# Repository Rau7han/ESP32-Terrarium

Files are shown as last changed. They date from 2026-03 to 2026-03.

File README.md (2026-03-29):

# 🌿 Smart Terrarium — ESP32

> An automated terrarium controller built with ESP32, featuring real-time sensor monitoring, a web dashboard, auto/manual relay control, NeoPixel lighting, and scheduled misting — all in one compact device.

<p align="center">
  Smart Terrarium
</p>

---

## 📖 What Is This?

This project turns a regular terrarium into a smart, self-maintaining environment for plants or reptiles. An ESP32 reads temperature, humidity, and soil moisture, then automatically controls a mist maker, ventilation fan, and water pump to keep everything in the ideal range.

You can monitor and control everything from a browser on your phone or computer — no app install needed.

---

## ✨ Features

- 🌡️ **Live sensor readings** — temperature (DHT11), humidity (DHT11), soil moisture (analog)
- 💧 **3 relay outputs** — Mist Maker, Ventilation Fan, Water Pump
- 🤖 **Auto mode** — relays switch on/off automatically based on your thresholds
- 🕐 **Scheduled misting** — set up to 10 timed mist events per day
- 📊 **Web dashboard** — real-time charts, history graphs, relay toggles, threshold editor
- 💡 **NeoPixel ring (12 LEDs)** — ambient colour shows system status at a glance
- 🖥️ **OLED display** — shows sensor values and relay states without a phone
- ⚡ **OTA (Over-the-Air) firmware updates** — update the code over WiFi, no USB needed
- 💾 **Persistent settings** — thresholds and mode survive power cycles
- 🔘 **Physical button** — short press toggles auto/manual; long press = emergency stop

---

## 🛠️ Hardware You Need

| Component | Details |
|---|---|
| ESP32 dev board | Any 30-pin board works |
| DHT11 sensor | Temperature + humidity |
| Soil moisture sensor | Capacitive or resistive, analog output |
| SSD1306 OLED display | 128×64, I²C |
| NeoPixel LED ring | 12 LEDs, WS2812B |
| 3-channel relay module | 5V, active-HIGH |
| Mist maker / ultrasonic atomiser | 5V or 12V |
| Mini water pump | For soil watering |
| Ventilation fan | 5V or 12V |
| Push button | Momentary, normally open |
| Power supply | 5V or 12V depending on your actuators |

---

## 🔌 Wiring

Connect everything to the ESP32 as follows:

| Signal | ESP32 Pin |
|---|---|
| DHT11 data | GPIO 2 |
| Soil sensor (analog out) | GPIO 36 (ADC1_CH0) |
| Button | GPIO 14 (uses internal pull-up) |
| Relay — Mist Maker | GPIO 25 |
| Relay — Ventilation Fan | GPIO 27 |
| Relay — Water Pump | GPIO 26 |
| NeoPixel data | GPIO 15 |
| OLED SDA | GPIO 5 |
| OLED SCL | GPIO 4 |

> **Note:** All relay outputs are active-HIGH. Connect the relay module's IN pins directly to the GPIO pins listed above.

---

## ⚙️ Software Setup

### 1. Install Arduino IDE and the ESP32 board package

Follow the official guide: [ESP32 Arduino Core](https://docs.espressif.com/projects/arduino-esp32/en/latest/installing.html)

### 2. Install the required libraries

Open **Sketch → Include Library → Manage Libraries** and install:

| Library | Version tested |
|---|---|
| `Adafruit SSD1306` | 2.5.x |
| `Adafruit GFX Library` | 1.11.x |
| `DHT sensor library` (Adafruit) | 1.4.x |
| `Adafruit NeoPixel` | 1.11.x |
| `ArduinoJson` | 6.x |

The following libraries come with the ESP32 board package and don't need separate installation: `WiFi`, `WebServer`, `ArduinoOTA`, `Preferences`.

### 3. Configure your WiFi credentials

Open `code/terrarium.ino` and update these two lines near the top:

```cpp
const char* WIFI_SSID = "YourNetworkName";
const char* WIFI_PASS = "YourPassword";
```

If you're not in India, also update the timezone offset (in seconds from UTC):

```cpp
const long GMT_OFFSET = 19800;  // IST = UTC+5:30  →  change to match your zone
```

### 4. Flash the ESP32

1. Connect the ESP32 via USB
2. Select your board: **Tools → Board → ESP32 Dev Module**
3. Select the correct COM port
4. Click **Upload**

### 5. Open the dashboard

1. Open the Serial Monitor at 115200 baud
2. Wait for the IP address to appear (e.g. `[WiFi] IP: 192.168.1.42`)
3. Type that address into any browser on the same network

> After the first flash you can update firmware wirelessly via **Sketch → Upload Using Programmer → OTA** — the device shows up as `terrarium-esp32`.

---

## 📟 OLED Display

The OLED cycles between two screens every 4 seconds:

| Screen | Shows |
|---|---|
| Page 1 | Temperature, Humidity, Soil moisture (with progress bar) |
| Page 2 | Relay states (Mist / Fan / Pump), WiFi status |

A mode indicator (`[AUTO]` or `[MANU]`) appears in the top corner at all times.

---

## 💡 NeoPixel Colour Guide

The 12 LEDs give you a quick at-a-glance status without looking at a screen:

| Colour | Meaning |
|---|---|
| 🟣 Purple | System is OK — all readings in range |
| 🔵 Blue (pixels 0–1) | Mist maker is ON |
| 🟠 Orange (pixels 4–5) | Fan is ON |
| 🩵 Cyan (pixels 8–9) | Pump is ON |
| 🔴 Red | Sensor error — check DHT11 |
| 🔵 Blue (ambient) | Soil is too dry |
| 🟢 Green | Soil is too wet |
| 🟠 Orange (ambient) | Temperature is too high |

---

## 🔘 Physical Button

| Press | Action |
|---|---|
| Short press | Toggle between Auto and Manual mode |
| Long press (2 s+) | Emergency stop — all relays turn OFF immediately |

---

## 🌐 Web Dashboard

Type the ESP32's IP address into any browser to open the dashboard. No app or internet connection needed — it runs entirely on the device.

<p align="center">
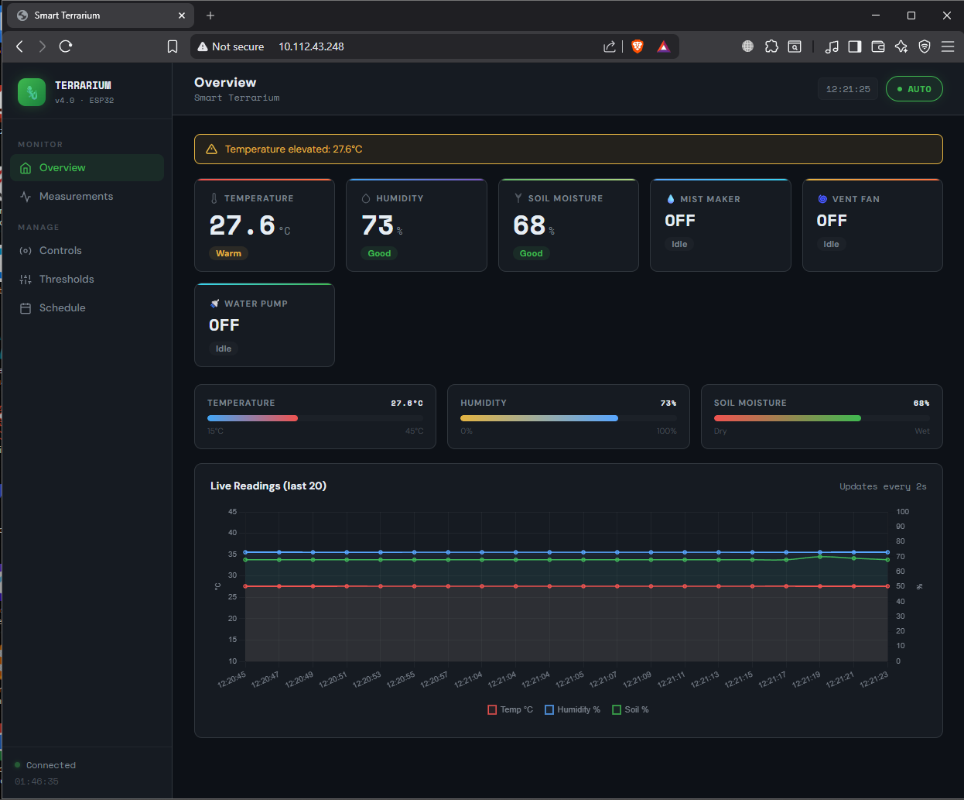
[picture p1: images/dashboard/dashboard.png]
Main Dashboard
  
  <br><em>Main dashboard — live sensor cards update every 2 seconds</em>
</p>

<p align="center">
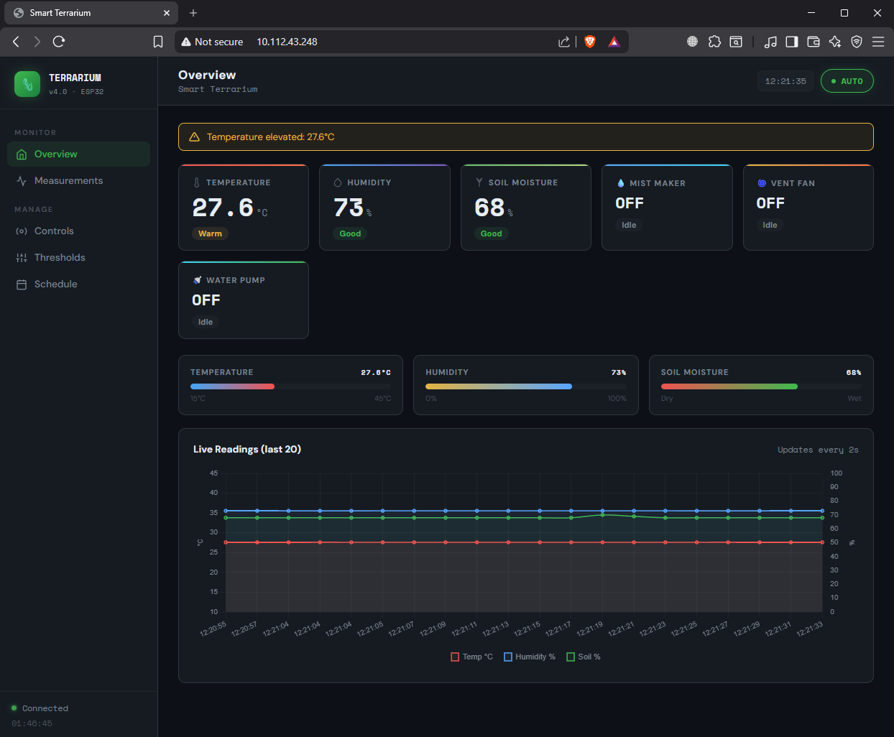
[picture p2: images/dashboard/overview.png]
Overview Panel
  
  <br><em>Overview panel showing all sensor and relay status</em>
</p>

<p align="center">
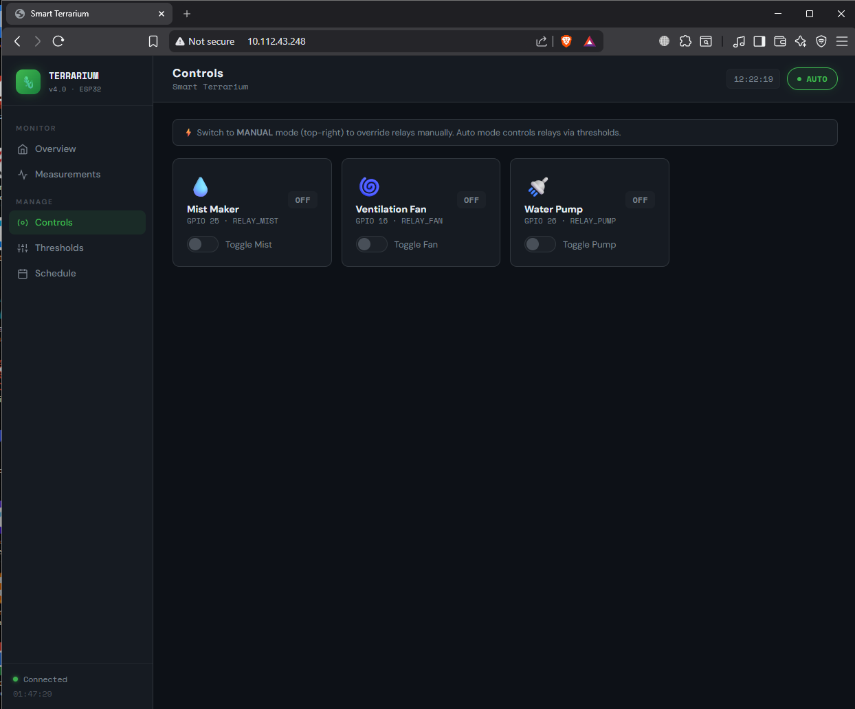
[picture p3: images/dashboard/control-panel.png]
Control Panel
  
  <br><em>Manual relay control panel — toggle Mist, Fan, and Pump individually</em>
</p>

### Sensor History Charts

<p align="center">
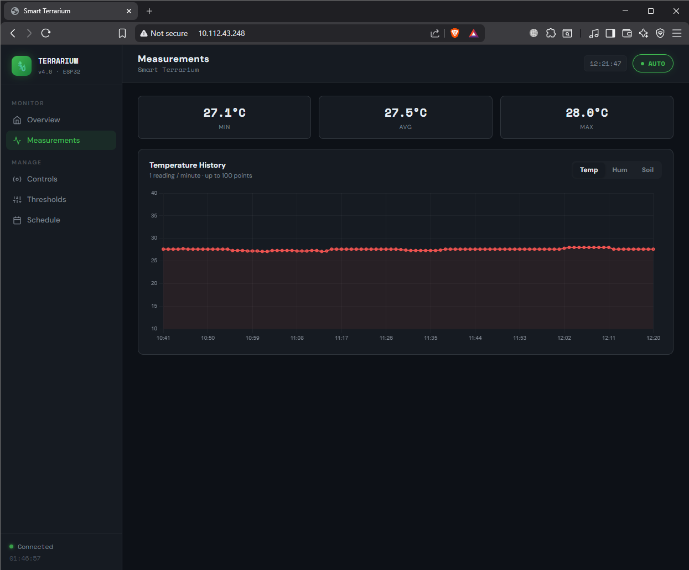
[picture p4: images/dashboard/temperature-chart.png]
Temperature History
  
  <br><em>Temperature history — one data point per minute, last 100 readings</em>
</p>

<p align="center">
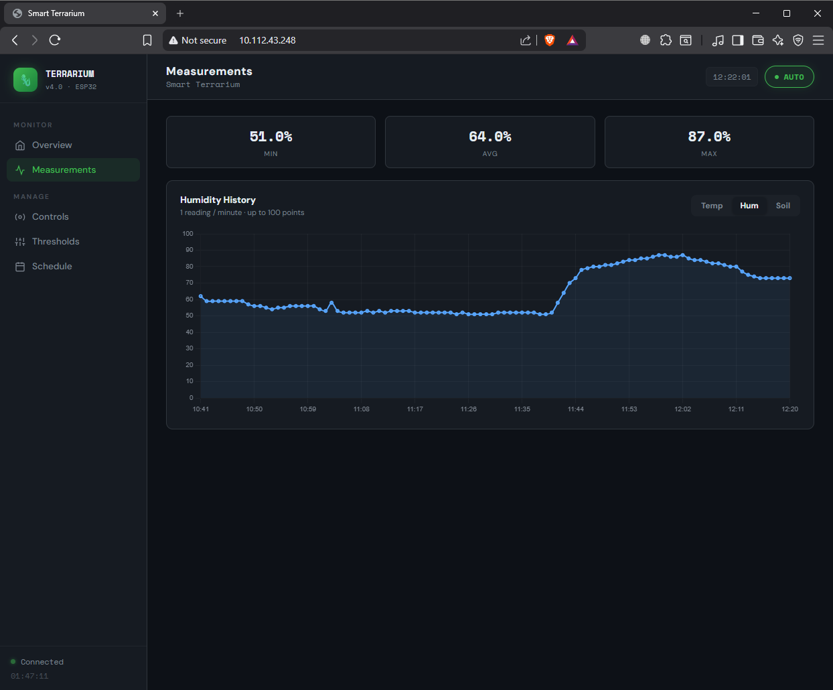
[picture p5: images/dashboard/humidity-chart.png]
Humidity History
  
  <br><em>Humidity history chart</em>
</p>

<p align="center">
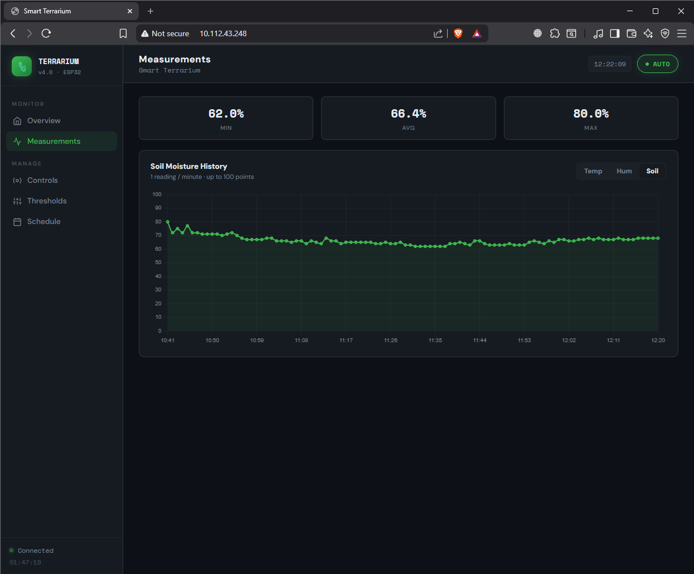
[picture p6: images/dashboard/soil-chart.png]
Soil Moisture History
  
  <br><em>Soil moisture history chart</em>
</p>

### Threshold Settings

<p align="center">
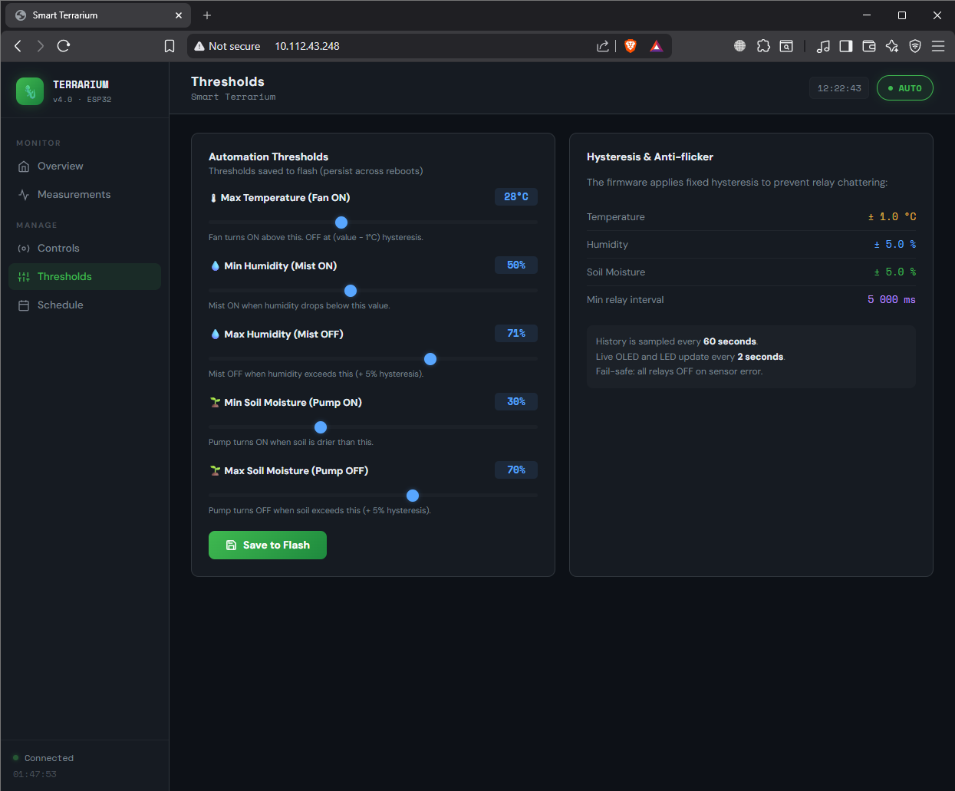
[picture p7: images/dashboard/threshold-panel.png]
Threshold Settings
  
  <br><em>Set your ideal ranges — values are saved to flash and survive power cuts</em>
</p>

### Scheduled Misting

<p align="center">
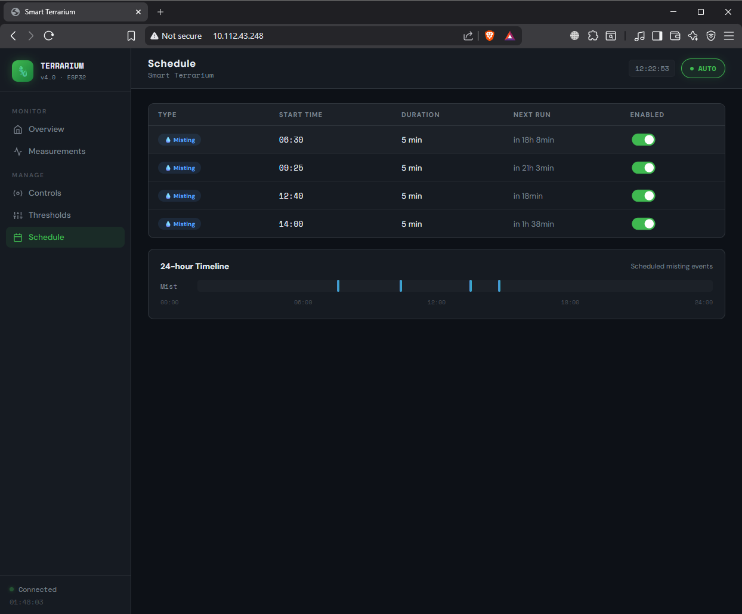
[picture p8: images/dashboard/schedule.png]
Misting Schedule
  
  <br><em>Schedule up to 10 daily misting events with custom duration</em>
</p>

---

## 📷 It Working in Real Life

<p align="center">
  Full Setup Running
  <br><em>The complete setup running — OLED lit, NeoPixels on</em>
</p>

<p align="center">
  Temperature Reading
  &nbsp;&nbsp;
  Humidity Reading
  <br><em>Left: temperature reading on the OLED &nbsp;|&nbsp; Right: humidity reading</em>
</p>

<p align="center">
  Soil Moisture Reading
  &nbsp;&nbsp;
  Threshold Display
  <br><em>Left: soil moisture sensor in action &nbsp;|&nbsp; Right: threshold display</em>
</p>

---

## 🖨️ 3D Printed Parts

The `3D_files/` folder contains an STL file for a custom **Aromizer housing** (`Aromizer.stl`) that mounts the ultrasonic mist maker neatly inside the terrarium.

---

## 📡 REST API Reference

The ESP32 exposes a simple JSON API, useful if you want to integrate it with Home Assistant or build your own UI.

| Method | Endpoint | Description |
|---|---|---|
| `GET` | `/api/live` | Current sensor readings and relay states |
| `GET` | `/api/history` | Last 100 readings (1 per minute) |
| `GET` | `/api/thresholds` | Current threshold values |
| `POST` | `/api/thresholds` | Update threshold values |
| `POST` | `/api/relay` | Turn a relay on/off (manual mode only) |
| `POST` | `/api/mode` | Switch between auto and manual mode |
| `GET` | `/api/events` | List scheduled misting events |
| `POST` | `/api/events` | Add or update a misting event |

**Example — read live data:**
```bash
curl http://192.168.1.42/api/live
```

**Example — turn on mist manually:**
```bash
curl -X POST http://192.168.1.42/api/relay \
     -H "Content-Type: application/json" \
     -d '{"relay":"mist","state":true}'
```

---

## 📁 Repository Structure

```
ESP32-Terrarium/
├── code/
│   └── terrarium.ino          # Main Arduino sketch
├── images/
│   ├── hardware/              # Real photos of the device
│   └── dashboard/             # Dashboard screenshots
├── 3D_files/
│   └── Aromizer.stl           # 3D printable mist maker housing
└── README.md
```

---

## 🤝 Contributing

Pull requests are welcome! If you add a new feature or fix a bug, please keep the code style consistent (the existing comments and section separators make it easy to follow).

---

## 📜 License

This project is open source. Feel free to use, modify, and share it for personal or educational purposes.

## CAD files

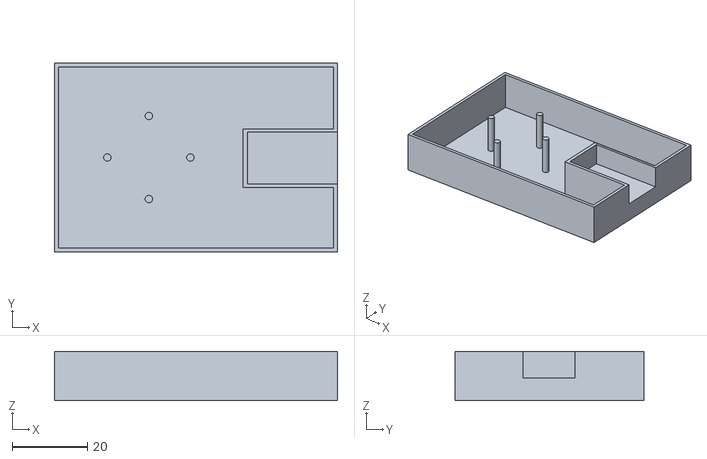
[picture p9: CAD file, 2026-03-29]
3D_files/Aromizer.stl
75.0 x 50.0 x 13.0

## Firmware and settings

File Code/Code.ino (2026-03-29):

// ╔══════════════════════════════════════════════════════════════╗
// ║          SMART TERRARIUM v4.0 — ESP32                       ║
// ║  Features: DHT11 · Soil · OLED · NeoPixel · 3x Relay       ║
// ║  WiFi Dashboard · Auto/Manual · Scheduled Misting    ║
// ╚══════════════════════════════════════════════════════════════╝

// ── Libraries ──────────────────────────────────────────────────
#include <Wire.h>
#include <Adafruit_GFX.h>
#include <Adafruit_SSD1306.h>
#include <DHT.h>
#include <Adafruit_NeoPixel.h>
#include <WiFi.h>
#include <WebServer.h>
#include <ArduinoJson.h>
#include <ArduinoOTA.h>
#include <Preferences.h>
#include <time.h>

// ── OLED ───────────────────────────────────────────────────────
#define I2C_SDA      5
#define I2C_SCL      4
#define OLED_W     128
#define OLED_H      64
Adafruit_SSD1306 display(OLED_W, OLED_H, &Wire, -1);

// ── DHT ────────────────────────────────────────────────────────
#define DHTPIN   2
#define DHTTYPE  DHT11
DHT dht(DHTPIN, DHTTYPE);

// ── Pins ───────────────────────────────────────────────────────
#define SOIL_PIN    36   // ADC1_CH0 — input-only
#define BUTTON_PIN  14   // INPUT_PULLUP
#define RELAY_MIST  25   // Mist Maker
#define RELAY_FAN   27   // Ventilation Fan
#define RELAY_PUMP  26   // Water Pump (NEW)
#define NEO_PIN     15   // NeoPixel data
#define NEO_COUNT   12

// ── Soil ADC calibration ───────────────────────────────────────
#define SOIL_DRY   4095
#define SOIL_WET   1800

// ── NeoPixel ───────────────────────────────────────────────────
Adafruit_NeoPixel ring(NEO_COUNT, NEO_PIN, NEO_GRB + NEO_KHZ800);

// ── WiFi / NTP ─────────────────────────────────────────────────
const char* WIFI_SSID   = "ESP";
const char* WIFI_PASS   = "abcd1234";
const char* NTP_SERVER  = "pool.ntp.org";
const long  GMT_OFFSET  = 19800;   // IST = UTC+5:30
const int   DST_OFFSET  = 0;

WebServer   server(80);
Preferences prefs;
bool        ntpSynced = false;

// ── Timing constants ───────────────────────────────────────────
// One reading per minute stored in history; live display refreshes every 2s
const unsigned long SENSOR_INTERVAL  = 60000UL;  // 60 s — history samples
const unsigned long LIVE_INTERVAL    = 2000UL;   // 2 s  — live readings (OLED/LED)
const unsigned long DISPLAY_INTERVAL = 500UL;    // 0.5 s — OLED refresh

// Relay anti-flicker: minimum ms between toggling the same relay
const unsigned long RELAY_MIN_INTERVAL = 5000UL; // 5 s

// ── Hysteresis ─────────────────────────────────────────────────
// Applied on top of threshold values so relays don't rapid-toggle
// Fan ON  if temp > tempMax,  OFF if temp < tempMax - TEMP_HYST
// Mist ON if hum  < humMin,   OFF if hum  > humMin  + HUM_HYST
// Pump ON if soil < soilMin,  OFF if soil > soilMin + SOIL_HYST
#define TEMP_HYST   1.0f   // °C
#define HUM_HYST    5.0f   // %
#define SOIL_HYST   5      // %

// ── Sensor data ────────────────────────────────────────────────
struct Reading {
    float    temp;
    float    hum;
    int      soil;
    uint32_t epoch;  // Unix timestamp (or seconds since boot)
};

#define HIST_SIZE 100
Reading  history[HIST_SIZE];
int      histHead  = 0;
int      histCount = 0;

struct Live {
    float temp  = 0;
    float hum   = 0;
    int   soil  = 0;
    bool  dhtOk = false;
};
Live live;

// ── Relay state ────────────────────────────────────────────────
struct Relays {
    bool mist = false;
    bool fan  = false;
    bool pump = false;
};
Relays relays;

// Anti-flicker: last time each relay was toggled
unsigned long lastToggleMist = 0;
unsigned long lastToggleFan  = 0;
unsigned long lastTogglePump = 0;

// ── Mode ───────────────────────────────────────────────────────
bool autoMode = false;

// ── Auto thresholds (persistent) ──────────────────────────────
struct Thresholds {
    float tempMax  = 30.0f;
    float humMin   = 50.0f;
    float humMax   = 80.0f;
    int   soilMin  = 30;
    int   soilMax  = 70;
};
Thresholds thresh;

// ── Scheduled misting events ───────────────────────────────────
#define MAX_EVENTS 10
struct MistEvent {
    int  hour;
    int  minute;
    int  durationMin;
    bool enabled;
};
MistEvent mistEvents[MAX_EVENTS] = {
    { 6, 30, 5, true },
    { 9, 25, 5, true },
    {12, 40, 5, true },
    {14,  0, 5, true },
};
int           eventCount = 4;
unsigned long mistStopAt = 0;

// ── Button debounce ────────────────────────────────────────────
const unsigned long DEBOUNCE_MS   = 50;
const unsigned long LONG_PRESS_MS = 2000;

bool          btnRaw      = false;
bool          btnStable   = false;
bool          btnDown     = false;
unsigned long btnDownAt   = 0;
unsigned long btnDebounce = 0;

// ── Timing trackers ────────────────────────────────────────────
unsigned long lastSensor  = 0;   // history write
unsigned long lastLive    = 0;   // live read (OLED / LED)
unsigned long lastDisplay = 0;   // OLED repaint

// ── OLED animation ────────────────────────────────────────────
int oledPage = 0;   // 0=overview, 1=relays, cycles every 4 s

// ── Forward declarations ───────────────────────────────────────
void connectWiFi();
void syncNTP();
String timestamp();
uint32_t epochNow();
void loadPrefs();
void savePrefs();
void setupRoutes();
void sendJSON(int code, const String& j);
void readSensors();
void runAutoControl();
void checkScheduledMisting();
void setRelay(bool& state, int pin, bool on, const char* name, unsigned long& lastToggle);
void handleButton();
void updateOLED();
void updateNeoPixel();
void printBanner();

// ════════════════════════════════════════════════════════════════
//  SETUP
// ════════════════════════════════════════════════════════════════
void setup() {
    Serial.begin(115200);
    delay(300);
    printBanner();

    // Persistent storage
    prefs.begin("terrarium", false);
    loadPrefs();

    // I2C + OLED
    Wire.begin(I2C_SDA, I2C_SCL);
    delay(80);
    bool oledOk = display.begin(SSD1306_SWITCHCAPVCC, 0x3C);
    if (!oledOk) Serial.println("[OLED] Init failed");
    display.setTextColor(WHITE);
    display.clearDisplay();
    display.setTextSize(1);
    display.setCursor(0,  0); display.println("SMART TERRARIUM v4");
    display.setCursor(0, 12); display.println("Initializing...");
    display.display();

    // Sensors
    dht.begin();
    analogSetPinAttenuation(SOIL_PIN, ADC_11db);

    // NeoPixel
    ring.begin(); ring.clear(); ring.show();

    // Button
    pinMode(BUTTON_PIN, INPUT_PULLUP);

    // Relays — ALL OFF at start (fail-safe)
    pinMode(RELAY_MIST, OUTPUT); digitalWrite(RELAY_MIST, LOW);
    pinMode(RELAY_FAN,  OUTPUT); digitalWrite(RELAY_FAN,  LOW);
    pinMode(RELAY_PUMP, OUTPUT); digitalWrite(RELAY_PUMP, LOW);

    // WiFi
    connectWiFi();

    if (WiFi.status() == WL_CONNECTED) {
        display.clearDisplay();
        display.setTextSize(1);
        display.setCursor(0,  0); display.println("WiFi Connected!");
        display.setCursor(0, 12); display.println("IP:");
        display.setTextSize(1);
        display.setCursor(0, 22); display.println(WiFi.localIP().toString());
        display.display();
        delay(2000);
    }

    syncNTP();

    // OTA
    ArduinoOTA.setHostname("terrarium-esp32");
    ArduinoOTA.onStart([]() {
        relays.mist = relays.fan = relays.pump = false;
        digitalWrite(RELAY_MIST, LOW);
        digitalWrite(RELAY_FAN,  LOW);
        digitalWrite(RELAY_PUMP, LOW);
        Serial.println("[OTA] Starting...");
    });
    ArduinoOTA.begin();

    setupRoutes();
    server.begin();

    // Do one immediate live read so OLED isn't blank
    readSensors(true);

    Serial.println("[SETUP] Complete");
}

// ════════════════════════════════════════════════════════════════
//  LOOP
// ════════════════════════════════════════════════════════════════
void loop() {
    ArduinoOTA.handle();
    server.handleClient();
    handleButton();

    unsigned long now = millis();

    // ── Live read every 2 s (for OLED / NeoPixel / auto-control) ──
    if (now - lastLive >= LIVE_INTERVAL) {
        readSensors(false);   // false = don't push to history
        if (autoMode)  runAutoControl();
        if (ntpSynced) checkScheduledMisting();

        // Stop scheduled mist when timer expires
        if (mistStopAt && now >= mistStopAt) {
            setRelay(relays.mist, RELAY_MIST, false, "Mist(sched-stop)", lastToggleMist);
            mistStopAt = 0;
        }
        lastLive = now;
    }

    // ── History write every 60 s ───────────────────────────────
    if (now - lastSensor >= SENSOR_INTERVAL) {
        // Push current live reading into history ring buffer
        Reading r;
        r.temp  = live.temp;
        r.hum   = live.hum;
        r.soil  = live.soil;
        r.epoch = epochNow();
        history[histHead] = r;
        histHead = (histHead + 1) % HIST_SIZE;
        if (histCount < HIST_SIZE) histCount++;
        Serial.printf("[History] Stored %.1f°C  %.0f%%  Soil:%d%%\n", live.temp, live.hum, live.soil);
        lastSensor = now;
    }

    // ── OLED + LED refresh ────────────────────────────────────
    if (now - lastDisplay >= DISPLAY_INTERVAL) {
        updateOLED();
        updateNeoPixel();
        lastDisplay = now;
    }

    // ── Non-blocking WiFi reconnect ───────────────────────────
    if (WiFi.status() != WL_CONNECTED) {
        static unsigned long lastRetry = 0;
        if (now - lastRetry > 10000) {
            lastRetry = now;
            WiFi.disconnect();
            WiFi.begin(WIFI_SSID, WIFI_PASS);
        }
    }

    delay(5);
}

// ════════════════════════════════════════════════════════════════
//  WIFI & NTP
// ════════════════════════════════════════════════════════════════
void connectWiFi() {
    Serial.printf("[WiFi] Connecting to %s\n", WIFI_SSID);
    WiFi.mode(WIFI_STA);
    WiFi.begin(WIFI_SSID, WIFI_PASS);
    unsigned long t = millis();
    while (WiFi.status() != WL_CONNECTED && millis() - t < 15000) {
        delay(300); Serial.print(".");
    }
    if (WiFi.status() == WL_CONNECTED)
        Serial.printf("\n[WiFi] IP: %s\n", WiFi.localIP().toString().c_str());
    else
        Serial.println("\n[WiFi] Failed — offline mode");
}

void syncNTP() {
    if (WiFi.status() != WL_CONNECTED) return;
    configTime(GMT_OFFSET, DST_OFFSET, NTP_SERVER);
    struct tm t;
    if (getLocalTime(&t, 5000)) {
        ntpSynced = true;
        char buf[32];
        strftime(buf, sizeof(buf), "%Y-%m-%d %H:%M:%S", &t);
        Serial.printf("[NTP] %s\n", buf);
    } else {
        Serial.println("[NTP] Sync failed");
    }
}

String timestamp() {
    if (ntpSynced) {
        struct tm t;
        if (getLocalTime(&t)) {
            char buf[32];
            strftime(buf, sizeof(buf), "%Y-%m-%dT%H:%M:%S", &t);
            return String(buf);
        }
    }
    return String(millis());
}

uint32_t epochNow() {
    if (ntpSynced) {
        struct tm t;
        if (getLocalTime(&t)) return (uint32_t)mktime(&t);
    }
    return (uint32_t)(millis() / 1000);
}

// ════════════════════════════════════════════════════════════════
//  PERSISTENT STORAGE
// ════════════════════════════════════════════════════════════════
void loadPrefs() {
    thresh.tempMax = prefs.getFloat("tempMax", 30.0f);
    thresh.humMin  = prefs.getFloat("humMin",  50.0f);
    thresh.humMax  = prefs.getFloat("humMax",  80.0f);
    thresh.soilMin = prefs.getInt  ("soilMin", 30);
    thresh.soilMax = prefs.getInt  ("soilMax", 70);
    autoMode       = prefs.getBool ("autoMode", false);
    Serial.printf("[Prefs] Loaded: tempMax=%.1f humMin=%.0f humMax=%.0f soilMin=%d soilMax=%d auto=%d\n",
                  thresh.tempMax, thresh.humMin, thresh.humMax,
                  thresh.soilMin, thresh.soilMax, autoMode);
}

void savePrefs() {
    prefs.putFloat("tempMax", thresh.tempMax);
    prefs.putFloat("humMin",  thresh.humMin);
    prefs.putFloat("humMax",  thresh.humMax);
    prefs.putInt  ("soilMin", thresh.soilMin);
    prefs.putInt  ("soilMax", thresh.soilMax);
    prefs.putBool ("autoMode", autoMode);
    Serial.println("[Prefs] Saved");
}

// ════════════════════════════════════════════════════════════════
//  SENSOR READING
//  pushHistory=true  → write into ring buffer (every 60 s)
//  pushHistory=false → update live struct only (every 2 s)
// ════════════════════════════════════════════════════════════════
void readSensors(bool pushHistory) {
    // ── DHT ─────────────────────────────────────────────────
    float t = dht.readTemperature();
    float h = dht.readHumidity();
    bool  ok = (!isnan(t) && !isnan(h));

    // Fail-safe: if DHT fails and autoMode is on, turn off ALL relays
    if (!ok && autoMode) {
        if (live.dhtOk) {   // only act on transition to error
            Serial.println("[FAILSAFE] DHT error — all relays OFF");
            setRelay(relays.mist, RELAY_MIST, false, "FS-mist", lastToggleMist);
            setRelay(relays.fan,  RELAY_FAN,  false, "FS-fan",  lastToggleFan);
            setRelay(relays.pump, RELAY_PUMP, false, "FS-pump", lastTogglePump);
        }
    }
    live.dhtOk = ok;
    if (ok) { live.temp = t; live.hum = h; }
    else     Serial.println("[DHT] Read failed");

    // ── Soil ADC ────────────────────────────────────────────
    int raw  = analogRead(SOIL_PIN);
    live.soil = constrain(map(raw, SOIL_DRY, SOIL_WET, 0, 100), 0, 100);

    if (ok)
        Serial.printf("[Sensor] %.1f°C  %.0f%%  Soil:%d%%\n",
                      live.temp, live.hum, live.soil);
}

// ════════════════════════════════════════════════════════════════
//  AUTO CONTROL  (hysteresis + anti-flicker)
// ════════════════════════════════════════════════════════════════
void runAutoControl() {
    if (!live.dhtOk) return;   // fail-safe: never actuate on bad data
    unsigned long now = millis();

    // ── Mist (humidity) ─────────────────────────────────────
    if (!relays.mist && live.hum < thresh.humMin) {
        if (now - lastToggleMist >= RELAY_MIN_INTERVAL)
            setRelay(relays.mist, RELAY_MIST, true, "Mist(auto-on)", lastToggleMist);
    } else if (relays.mist && live.hum >= (thresh.humMin + HUM_HYST)) {
        if (now - lastToggleMist >= RELAY_MIN_INTERVAL)
            setRelay(relays.mist, RELAY_MIST, false, "Mist(auto-off)", lastToggleMist);
    }

    // ── Fan (temperature) ────────────────────────────────────
    if (!relays.fan && live.temp > thresh.tempMax) {
        if (now - lastToggleFan >= RELAY_MIN_INTERVAL)
            setRelay(relays.fan, RELAY_FAN, true, "Fan(auto-on)", lastToggleFan);
    } else if (relays.fan && live.temp <= (thresh.tempMax - TEMP_HYST)) {
        if (now - lastToggleFan >= RELAY_MIN_INTERVAL)
            setRelay(relays.fan, RELAY_FAN, false, "Fan(auto-off)", lastToggleFan);
    }

    // ── Pump (soil moisture) ─────────────────────────────────
    if (!relays.pump && live.soil < thresh.soilMin) {
        if (now - lastTogglePump >= RELAY_MIN_INTERVAL)
            setRelay(relays.pump, RELAY_PUMP, true, "Pump(auto-on)", lastTogglePump);
    } else if (relays.pump && live.soil >= (thresh.soilMin + SOIL_HYST)) {
        if (now - lastTogglePump >= RELAY_MIN_INTERVAL)
            setRelay(relays.pump, RELAY_PUMP, false, "Pump(auto-off)", lastTogglePump);
    }
}

// ════════════════════════════════════════════════════════════════
//  SCHEDULED MISTING
// ════════════════════════════════════════════════════════════════
void checkScheduledMisting() {
    struct tm t;
    if (!getLocalTime(&t)) return;
    int h = t.tm_hour, m = t.tm_min, s = t.tm_sec;
    if (s != 0) return;   // only fire at exact minute boundary

    for (int i = 0; i < eventCount; i++) {
        if (!mistEvents[i].enabled) continue;
        if (mistEvents[i].hour == h && mistEvents[i].minute == m) {
            setRelay(relays.mist, RELAY_MIST, true, "Mist(sched)", lastToggleMist);
            mistStopAt = millis() + (unsigned long)mistEvents[i].durationMin * 60000UL;
            Serial.printf("[Sched] Mist ON for %d min\n", mistEvents[i].durationMin);
        }
    }
}

// ════════════════════════════════════════════════════════════════
//  RELAY HELPER  (with anti-flicker guard)
// ════════════════════════════════════════════════════════════════
void setRelay(bool& state, int pin, bool on, const char* name, unsigned long& lastToggle) {
    // Anti-flicker: skip if toggled too recently (unless turning off)
    // We always allow turning OFF (safety), but guard turning ON
    unsigned long now = millis();
    if (on && (now - lastToggle < RELAY_MIN_INTERVAL)) {
        Serial.printf("[Relay] %s ON skipped (anti-flicker)\n", name);
        return;
    }
    state = on;
    digitalWrite(pin, on ? HIGH : LOW);
    lastToggle = now;
    Serial.printf("[Relay] %s %s\n", name, on ? "ON" : "OFF");
}

// ════════════════════════════════════════════════════════════════
//  BUTTON — GPIO 14, INPUT_PULLUP
//  Short press  : toggle Auto / Manual mode
//  Long press   : EMERGENCY stop (all relays OFF)
// ════════════════════════════════════════════════════════════════
void handleButton() {
    bool reading = (digitalRead(BUTTON_PIN) == LOW);
    unsigned long now = millis();

    if (reading != btnRaw) { btnDebounce = now; btnRaw = reading; }
    if (now - btnDebounce < DEBOUNCE_MS) return;

    bool prev = btnStable;
    btnStable = reading;

    if (btnStable && !prev) {
        btnDown   = true;
        btnDownAt = now;
    }

    if (!btnStable && prev && btnDown) {
        btnDown = false;
        unsigned long dur = now - btnDownAt;

        if (dur >= LONG_PRESS_MS) {
            setRelay(relays.mist, RELAY_MIST, false, "EMERGENCY", lastToggleMist);
            setRelay(relays.fan,  RELAY_FAN,  false, "EMERGENCY", lastToggleFan);
            setRelay(relays.pump, RELAY_PUMP, false, "EMERGENCY", lastTogglePump);
            mistStopAt = 0;
            Serial.println("[Button] EMERGENCY STOP");
        } else {
            autoMode = !autoMode;
            savePrefs();
            Serial.printf("[Button] Mode → %s\n", autoMode ? "AUTO" : "MANUAL");
        }
    }
}

// ════════════════════════════════════════════════════════════════
//  OLED — alternates between two pages every 4 s
//  Page 0: Temp / Hum / Soil / Mode
//  Page 1: Relay states (Mist / Fan / Pump) + WiFi
// ════════════════════════════════════════════════════════════════
void updateOLED() {
    static unsigned long lastPageSwitch = 0;
    if (millis() - lastPageSwitch > 4000) {
        oledPage = (oledPage + 1) % 2;
        lastPageSwitch = millis();
    }

    display.clearDisplay();
    display.setTextSize(1);

    // ── Title bar ──────────────────────────────────────────
    display.setCursor(0, 0);
    display.print("TERRARIUM ");
    display.print(autoMode ? "[AUTO]" : "[MANU]");
    display.drawLine(0, 9, 127, 9, WHITE);

    if (oledPage == 0) {
        // ── Sensors ───────────────────────────────────────
        if (!live.dhtOk) {
            display.setCursor(0, 14); display.println("DHT Error!");
        } else {
            display.setCursor(0, 14);
            display.print("Temp: "); display.print(live.temp, 1); display.print(" C");
            display.setCursor(0, 24);
            display.print("Hum:  "); display.print((int)live.hum); display.print(" %");
        }
        display.setCursor(0, 34);
        display.print("Soil: "); display.print(live.soil); display.print(" %");

        // Progress bar for soil
        int barW = map(live.soil, 0, 100, 0, 80);
        display.drawRect(44, 35, 82, 6, WHITE);
        if (barW > 0) display.fillRect(44, 35, barW, 6, WHITE);

    } else {
        // ── Relay status ──────────────────────────────────
        display.setCursor(0, 14);
        display.print("Mist:  "); display.println(relays.mist ? "ON " : "OFF");
        display.setCursor(0, 24);
        display.print("Fan:   "); display.println(relays.fan  ? "ON " : "OFF");
        display.setCursor(0, 34);
        display.print("Pump:  "); display.println(relays.pump ? "ON " : "OFF");
    }

    // ── Bottom status bar ─────────────────────────────────
    display.drawLine(0, 44, 127, 44, WHITE);
    display.setCursor(0, 48);
    display.print(WiFi.status() == WL_CONNECTED ? "WiFi:OK " : "WiFi:-- ");
    display.print(relays.mist ? "M" : "-");
    display.print(relays.fan  ? "F" : "-");
    display.print(relays.pump ? "P" : "-");

    // Page indicator dots
    display.fillCircle(oledPage == 0 ? 118 : 124, 52, 2, WHITE);
    display.drawCircle(oledPage == 0 ? 124 : 118, 52, 2, WHITE);

    display.display();
}
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
